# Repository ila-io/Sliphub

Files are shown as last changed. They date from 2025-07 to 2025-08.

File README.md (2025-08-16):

# Sliphub
A USB hub that I can slip on and off of the top of my Surface Pro! 

It has 2 USB A ports and 2 USB C ports, and will fit on the top of my surface pro alongside my [slipboard](https://github.com/ila-io/slipboard/)! I modeled this after the design I made for that, and am hoping it's the second of a suite of slip-on accessories for my laptop :D

I made it because the surface pro only has 2 USB C ports, which is basically unusable for any considerable amount of wired devices (i.e. using it in place of a desktop with monitors, input devices, etc), and I didn't have a USB hub already! 

### heres what the product looks like!

(my friend didnt print out the top of the case in time, but i'll update this once I have it!) 
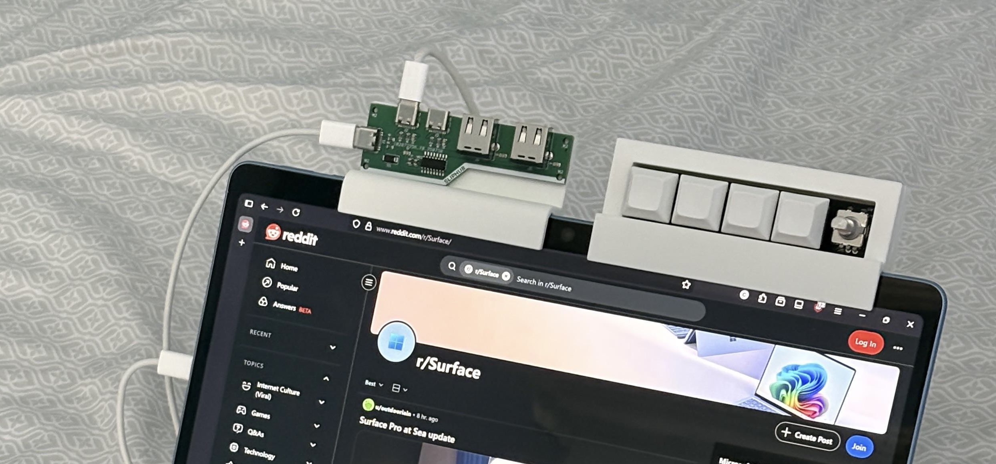
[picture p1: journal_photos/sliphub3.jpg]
sliphub irl


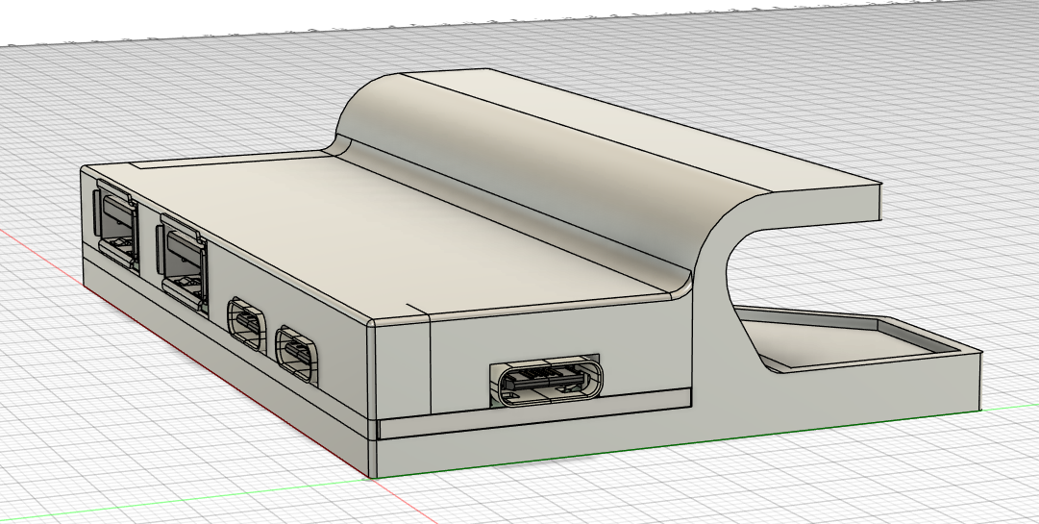
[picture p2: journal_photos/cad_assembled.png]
sliphub assembled

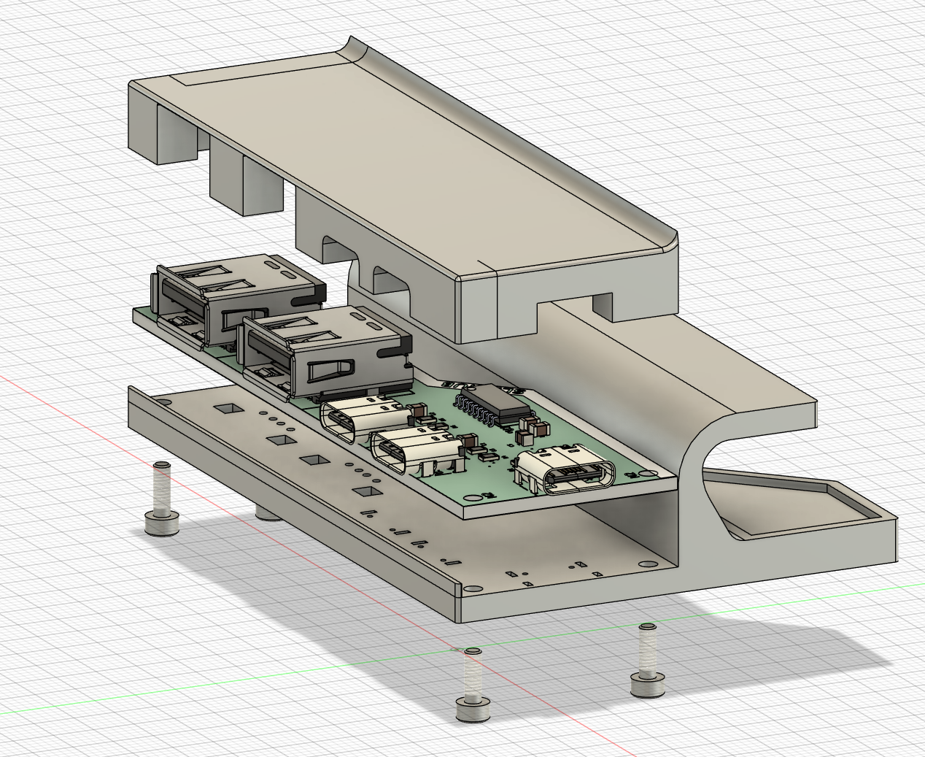
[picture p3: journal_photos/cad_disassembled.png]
sliphub disassembled

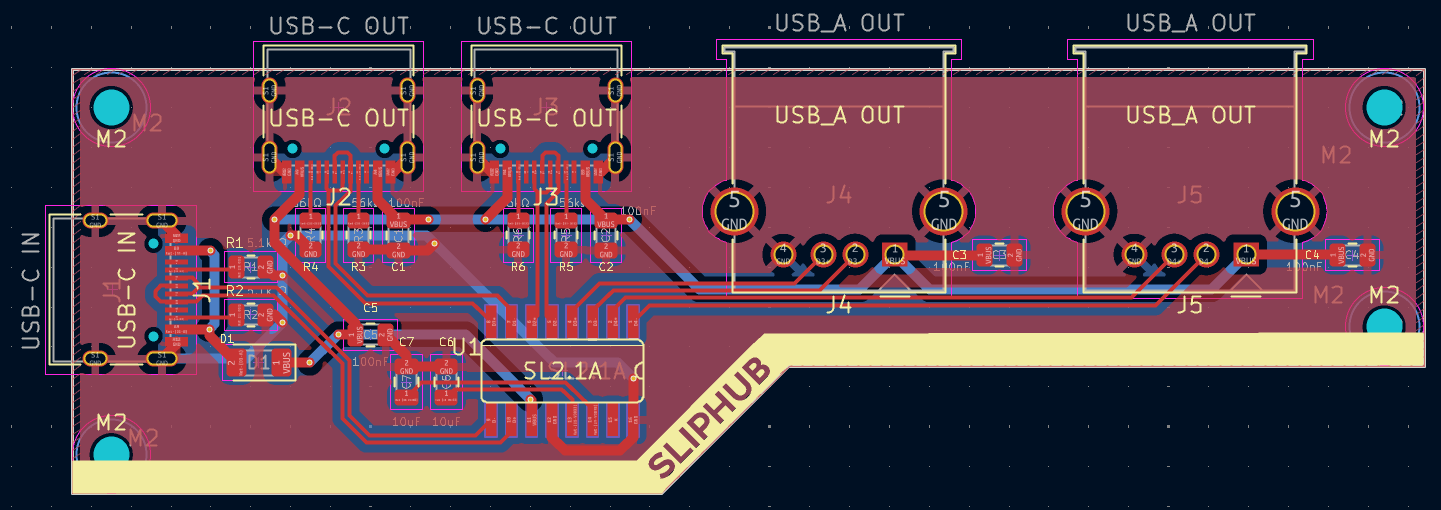
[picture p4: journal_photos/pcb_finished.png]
slipbub pcb routed

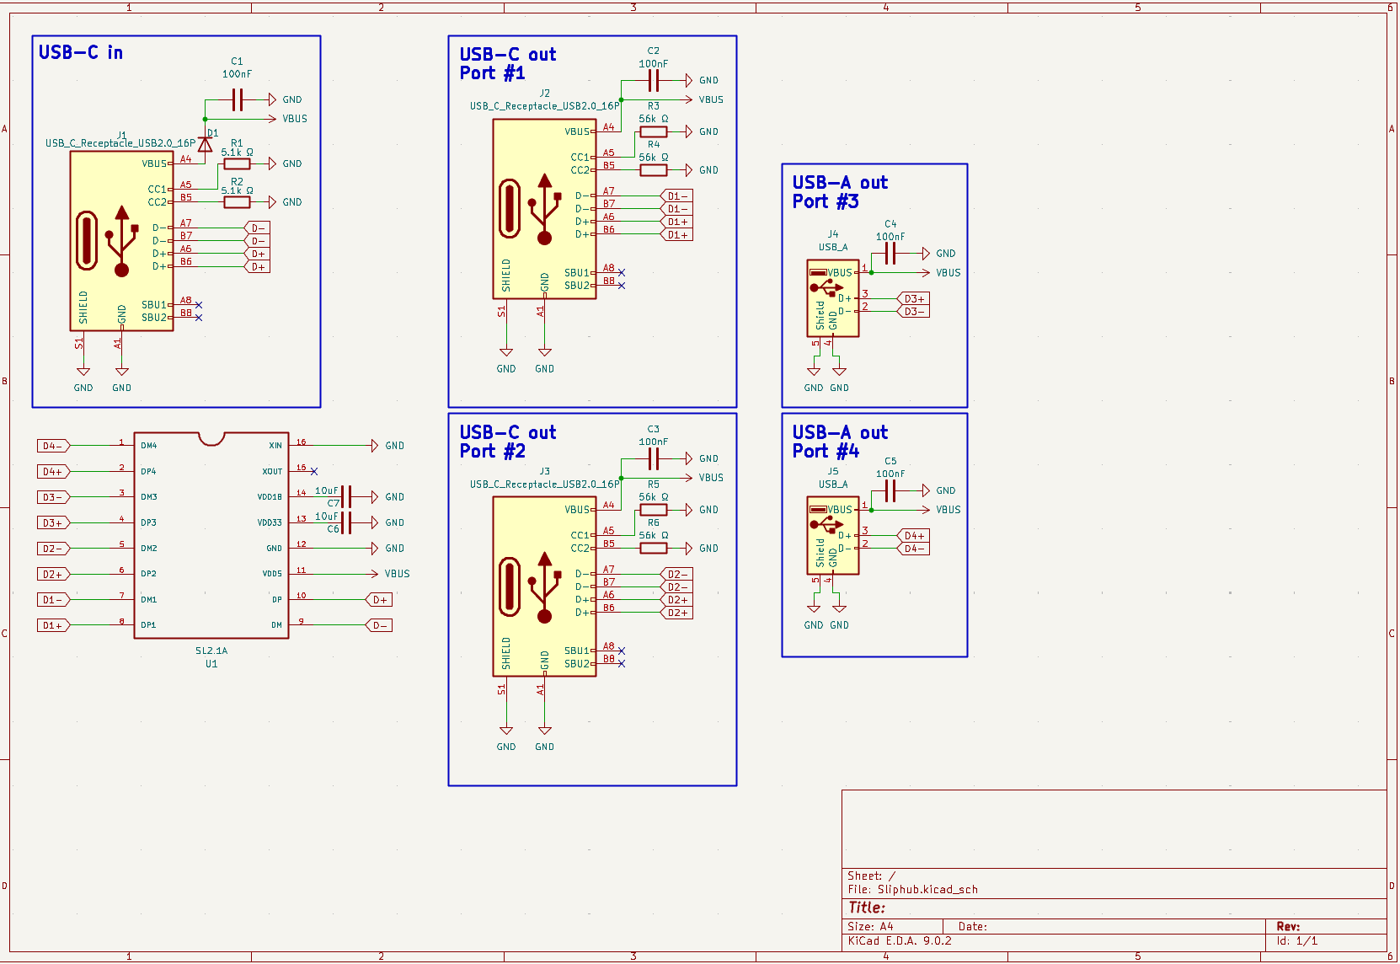
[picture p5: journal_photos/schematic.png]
sliphub schematic

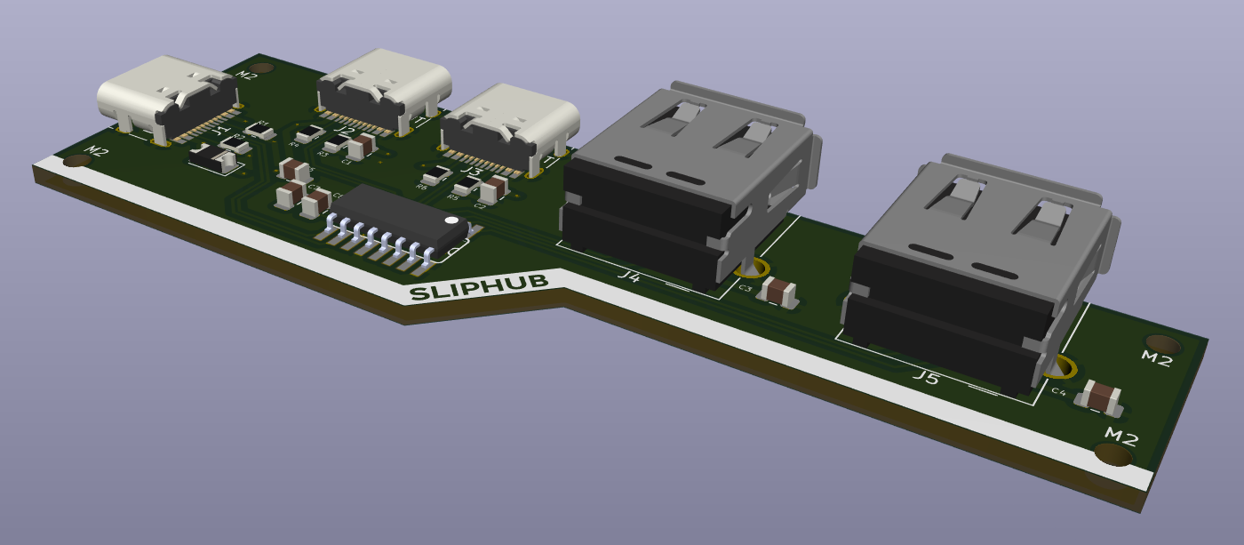
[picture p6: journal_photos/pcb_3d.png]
sliphub pcb 3d model


### [demo video!](https://youtu.be/sluuIp59PdY)

## BOM:
### PCBA BOM:
| item | count | LCSC number | cost  | LCSC link |
|---|---|---|---|---|
| USB-C Receptacle | 3 | C3197885 | $2.99 | https://lcsc.com/product-detail/USB-Connectors_JAE-DX07S016JA1R1500_C3197885.html |
| USB-A Receptacle | 2 | C2798029 | $1.63 | https://lcsc.com/product-detail/USB-Connectors_MOLEX-676430910_C2798029.html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 |
| SL2.1A | 1 | C192893 | $0.26 | https://lcsc.com/product-detail/USB-HUB-Controllers_CoreChips-SL2-1A_C192893.html |
| 100nF capacitor  | 5 | C48579599 | $0.25 | https://lcsc.com/product-detail/Multilayer-Ceramic-Capacitors-MLCC-SMD-SMT_AIDE-CAPACITOR-0805X7R104K101NT_C48579599.html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 |
| 10uF capacitor | 2 | C48579582 | $0.71 | https://lcsc.com/product-detail/Multilayer-Ceramic-Capacitors-MLCC-SMD-SMT_AIDE-CAPACITOR-0805X5R106K500NT_C48579582.html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  |
| 5.1k Ω resistor  | 2 | C27834 | $0.19 | https://lcsc.com/product-detail/Chip-Resistor-Surface-Mount_UNI-ROYAL-0805W8F5101T5E_C27834.html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 |
| 56k Ω resistor | 4 | C17756 | $0.19 | https://lcsc.com/product-detail/Chip-Resistor-Surface-Mount_UNI-ROYAL-0805W8F5602T5E_C17756.html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 |
| Diode | 1 | C154551 | $0.57 | https://lcsc.com/product-detail/Schottky-Diodes_onsemi-SS34_C154551.html?s_z=n_SS34 |
PCBA Cost | | |$37.83

### GENERAL BOM: 
| item | count | cost | link |
|---|---|---|---|
| PCBA | 2 (minimum order) | $37.83 | https://jlcpcb.com |
| M2 Heatset Inserts x50 | 1 |  $0.99 | https://www.aliexpress.us/item/3256803396040989.html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 |
| M2 Screws x50 | 1 |  $0.99 | https://www.aliexpress.us/item/3256802178253461.html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 |
| 1.5mm silicone rubber sheet | 1 | $4.76  | https://www.aliexpress.us/item/3256801236853786.html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 |
| total: | 5 | $44.75 | |

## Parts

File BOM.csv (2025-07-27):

item | count | cost | link
PCBA | 2 (minimum order) | $37.83 | https://jlcpcb.com
M2 Heatset Inserts x50 | 1 | $0.99 | https://www.aliexpress.us/item/3256803396040989.html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
M2 Screws x50 | 1 | $0.99 | https://www.aliexpress.us/item/3256802178253461.html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
1.5mm silicone rubber sheet | 1 | $4.76 | https://www.aliexpress.us/item/3256801236853786.html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
total: | 4 | $44.75

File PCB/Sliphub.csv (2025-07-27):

Id | Designator | Footprint | Quantity | Designation | Supplier and ref
1 | D1 | D_SMA | 1 | ~
2 | C2,C4,C5,C1,C3 | C_0805_2012Metric | 5 | 100nF
3 | J1 | USB_C_Receptacle_HRO_TYPE-C-31-M-12 | 1 | USB-C IN
4 | R2,R1 | R_0805_2012Metric | 2 | 5.1k Ω
5 | R3,R6,R5,R4 | R_0805_2012Metric | 4 | 56kΩ
6 | C7,C6 | C_0805_2012Metric | 2 | 10uF
7 | J3,J2 | USB_C_Receptacle_HRO_TYPE-C-31-M-12 | 2 | USB-C OUT
8 | J5,J4 | USB_A_Molex_67643_Horizontal | 2 | USB_A OUT
9 | U1 | SO16 | 1 | SL2.1A

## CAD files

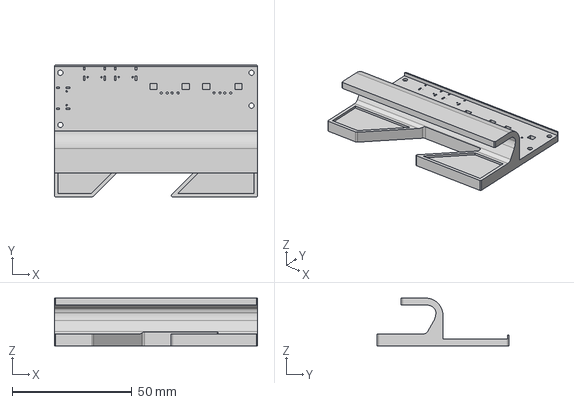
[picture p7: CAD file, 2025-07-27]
Case/case_bottom.step
84.7 x 55.0 x 20.0 mm

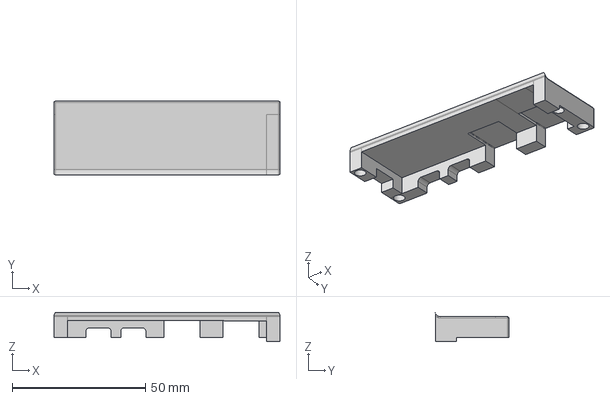
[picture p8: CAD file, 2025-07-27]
Production/case_top.step
84.7 x 27.6 x 11.0 mm

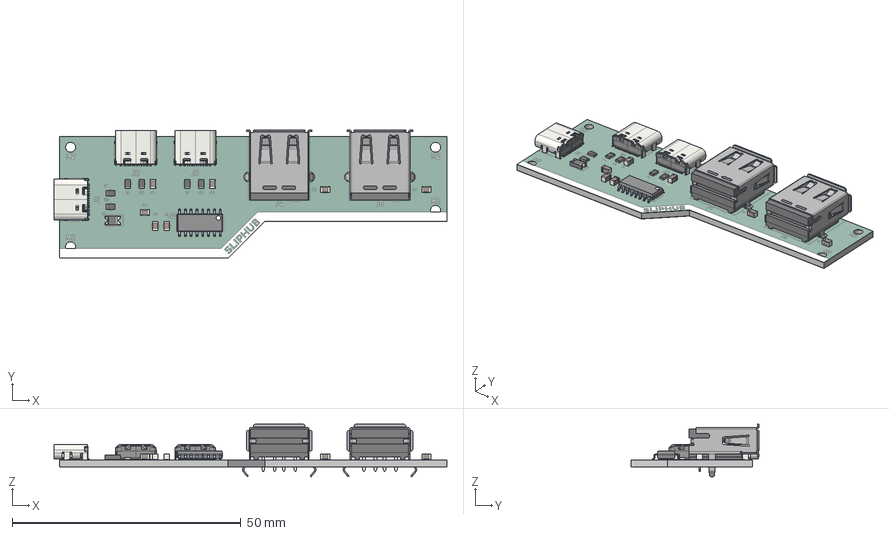
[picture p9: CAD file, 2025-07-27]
Case/SliphubPCB.step
85.9 x 28.0 x 11.5 mm
C_0805_2012Metric x 7
USB_C_Receptacle_GCT_USB4105-xx-A_16P_TopMnt_Horizontal x 3
D_1206_3216Metric
R_0805_2012Metric x 6
USB_A_Molex_67643_Horizontal x 2
SL2.1A
Sliphub_silkscreen
Sliphub_soldermask
Sliphub_PCB

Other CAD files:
Case/Sliphub_case.f3z

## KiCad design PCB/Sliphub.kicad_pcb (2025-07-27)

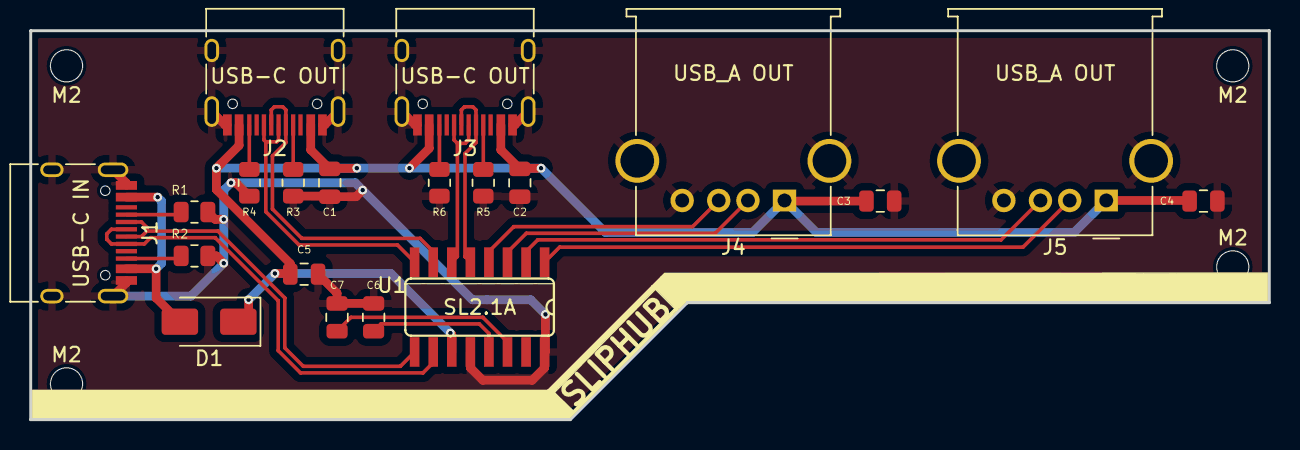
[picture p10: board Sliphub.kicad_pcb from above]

Board: 2 copper layers, 84.7 x 26.6 mm, 24 parts (0 on the bottom side), 21 nets.

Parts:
C1, C2, C3, C4, C5: 100nF; C_0805_2012Metric
C6, C7: 10uF; C_0805_2012Metric
D1: D_SMA
J1: USB-C IN; USB_C_Receptacle_HRO_TYPE-C-31-M-12
J2, J3: USB-C OUT; USB_C_Receptacle_HRO_TYPE-C-31-M-12
J4, J5: USB_A OUT; USB_A_Molex_67643_Horizontal
M2, M2#2, M2#3, M2#4: M2; MountingHole_2.2mm_M2
R1, R2: 5.1k Ω; R_0805_2012Metric
R3, R4, R5, R6: 56kΩ; R_0805_2012Metric
U1: SL2.1A; SO16

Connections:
D1+: J2.A6 (D+), J2.B6 (D+), U1.8 (DP1)
D1-: J2.A7 (D-), J2.B7 (D-), U1.7 (DM1)
D2+: J3.A6 (D+), J3.B6 (D+), U1.6 (DP2)
D2-: J3.A7 (D-), J3.B7 (D-), U1.5 (DM2)
D3+: J4.3 (D+), U1.4 (DP3)
D3-: J4.2 (D-), U1.3 (DM3)
D4+: J5.3 (D+), U1.2 (DP4)
D4-: J5.2 (D-), U1.1 (DM4)
D+: J1.A6 (D+), J1.B6 (D+), U1.10 (DP)
D-: J1.A7 (D-), J1.B7 (D-), U1.9 (DM)
GND: C1.2, C2.2, C3.2, C4.2, C5.2, C6.2, C7.2, J1.A1 (GND), J1.A12 (GND), J1.B1 (GND), J1.B12 (GND), J1.S1 (SHIELD), J2.A1 (GND), J2.A12 (GND), J2.B1 (GND), J2.B12 (GND), J2.S1 (SHIELD), J3.A1 (GND), J3.A12 (GND), J3.B1 (GND), J3.B12 (GND), J3.S1 (SHIELD), J4.4 (GND), J4.5 (Shield), J5.4 (GND), J5.5 (Shield), R1.2, R2.2, R3.2, R4.2, R5.2, R6.2, U1.12 (GND), U1.16 (XIN)
unnamed: D1.2 (A), J1.A4 (VBUS), J1.A9 (VBUS), J1.B4 (VBUS), J1.B9 (VBUS)
unnamed: J1.A5 (CC1), R1.1
unnamed: J1.B5 (CC2), R2.1
unnamed: J2.A5 (CC1), R3.1
unnamed: J2.B5 (CC2), R4.1
unnamed: J3.A5 (CC1), R5.1
unnamed: J3.B5 (CC2), R6.1
unnamed: C7.1, U1.14 (VDD18)
unnamed: C6.1, U1.13 (VDD33)
VBUS: C1.1, C2.1, C3.1, C4.1, C5.1, D1.1 (K), J2.A4 (VBUS), J2.A9 (VBUS), J2.B4 (VBUS), J2.B9 (VBUS), J3.A4 (VBUS), J3.A9 (VBUS), J3.B4 (VBUS), J3.B9 (VBUS), J4.1 (VBUS), J5.1 (VBUS), U1.11 (VDD5)

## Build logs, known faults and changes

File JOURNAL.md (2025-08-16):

---
title: Sliphub
author: Colin (@ila)
description: A USB Hub designed to slip on to the top of my Surface Pro 11!
created_at: 2025-7-23
total_time_spent: 11 horus
---

# July 23rd 
today i did some researach on USB hubs... initially i planned on having 2 USB A, 1 USB C, and 1 HDMI, but i learned that it was probably wise to avoid HDMI due to the complications that arise from implementation, so now its just another USB C port making for 1 of each type!

additionally i created my schematic :3
sliphub schematic
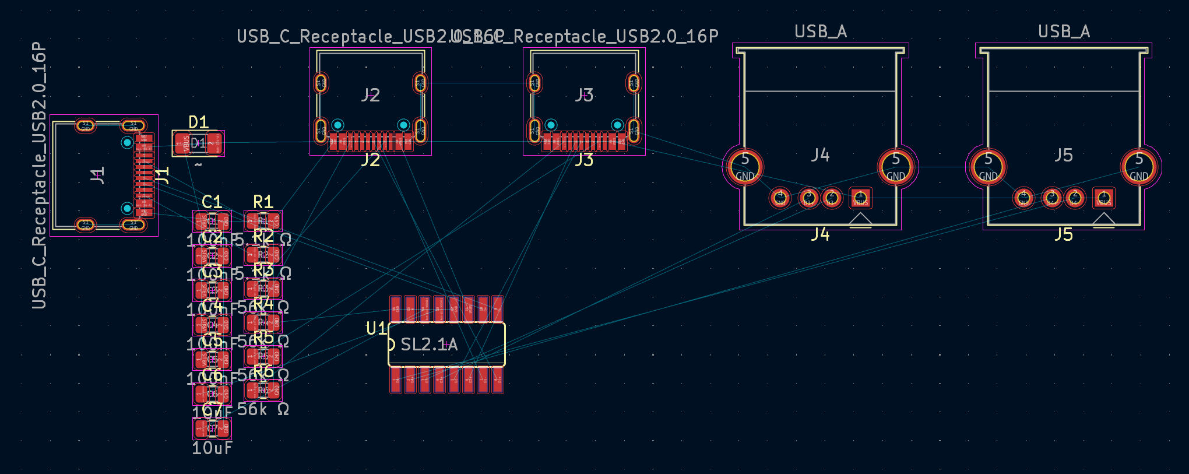
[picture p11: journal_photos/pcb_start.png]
slipbub pcb unrouted

sliphub pcb 3d model

### hours spent: 4

# July 24th
routed my pcb today! 

sliphub pcb routed

after that i made my case in fusion too! its supposed to mimic the look of my [slipboard](https://github.com/ila-io/slipboard/tree/main) hackpad, since im trying to build out a cohesive ecosystem of accesories for my surface pro! 

sliphub assembled
sliphub disassembled

now i'm all done, just have to upload all the files to github and submit! 

### Hours spent: 7

# August 8

got my PCB in today and picked up the bottom half of the case from my friend, but he didnt print the top half, and he moves out for college tomorrow so i cant get him to print it :sob: 
i can get it printed out pretty soon hopefully though! 

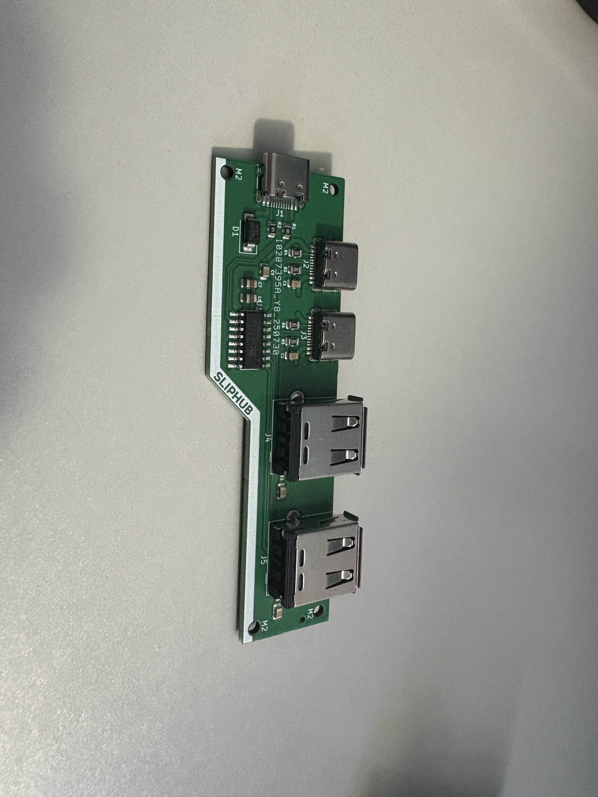
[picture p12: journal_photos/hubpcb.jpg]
sliphub pcb irl

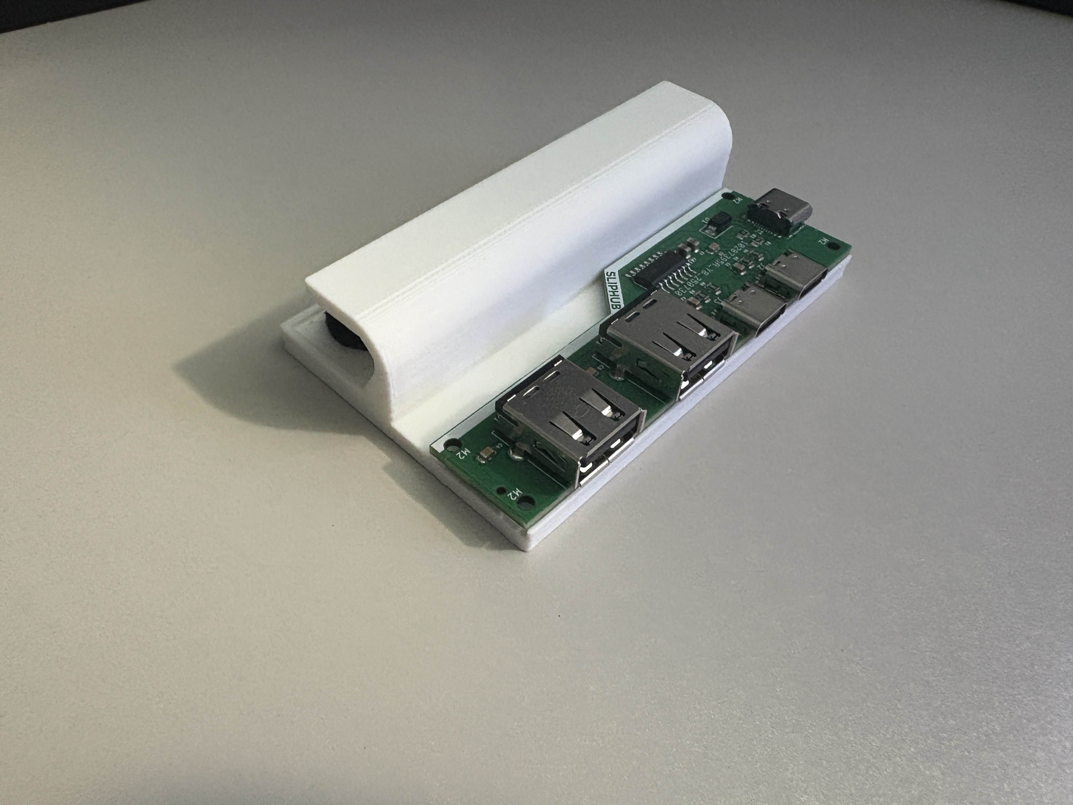
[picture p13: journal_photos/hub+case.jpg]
sliphub pcb+case irl


it took me like 5 minutes to slip it in and secure it, but it works perfectly!

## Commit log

2025-07-27 Add production, case, and pcb files
    [Sliphub.csv, Sliphub.kicad_pcb, Sliphub.kicad_sch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]
2025-07-27 add BOMs
    [BOM.csv, PCBA-BOM.csv]
2025-07-27 add BOM for JLCPCB for PCBA
    [Sliphub-BOM-JLCPCB.csv, Sliphub.kicad_sch]
